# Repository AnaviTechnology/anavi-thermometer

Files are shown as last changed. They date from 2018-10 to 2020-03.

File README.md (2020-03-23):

# ANAVI Thermometer

ANAVI Thermometer is an open source hardware development board that acts like a WiFi smart thermometer. It features:

* ESP8266 WiFi microcontroller
* DHT22 sensor for temperature and humidity
* Terminal for waterproof DS18B20 1-Wire temperature sensor
* Dedicated slot for I2C OLED display
* Slots for up to 3 plug and play I2C sensors for temperature, barometric pressure, humidity and light
* UART (Universal asynchronous receiver/transmitter) pins for debugging

The default open source firmware for ANAVI Thermometer written as an [Arduino sketch is also available at GitHub](https://github.com/AnaviTechnology/anavi-thermometer-sw).

# License

The project is released under the [Creative Commons Attribution-ShareAlike 4.0 International (CC BY-SA 4.0)](https://creativecommons.org/licenses/by-sa/4.0/).

Note: This is a human-readable summary of (and not a substitute for) the [license](https://creativecommons.org/licenses/by-sa/4.0/legalcode).

You are free to:

Share — copy and redistribute the material in any medium or format Adapt — remix, transform, and build upon the material for any purpose, even commercially. The licensor cannot revoke these freedoms as long as you follow the license terms. Under the following terms:

Attribution — You must give appropriate credit, provide a link to the license, and indicate if changes were made. You may do so in any reasonable manner, but not in any way that suggests the licensor endorses you or your use. ShareAlike — If you remix, transform, or build upon the material, you must distribute your contributions under the same license as the original. No additional restrictions — You may not apply legal terms or technological measures that legally restrict others from doing anything the license permits. Notices:

You do not have to comply with the license for elements of the material in the public domain or where your use is permitted by an applicable exception or limitation. No warranties are given. The license may not give you all of the permissions necessary for your intended use. For example, other rights such as publicity, privacy, or moral rights may limit how you use the material.

You will have to provide a link to the original creator of the project http://www.anavi.technology on any documentation or website.

Credit can be attributed through a link to the creator website: http://www.anavi.technology

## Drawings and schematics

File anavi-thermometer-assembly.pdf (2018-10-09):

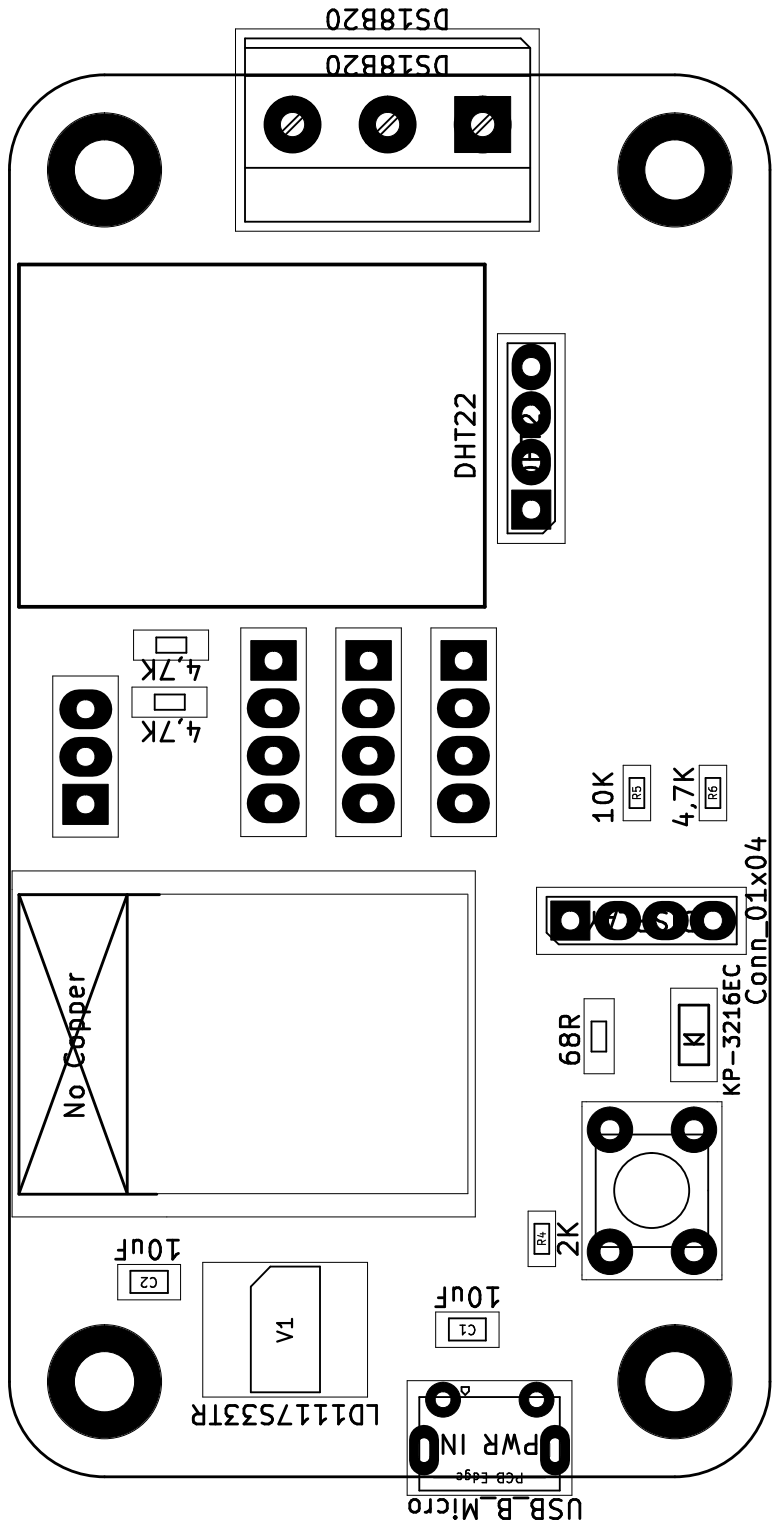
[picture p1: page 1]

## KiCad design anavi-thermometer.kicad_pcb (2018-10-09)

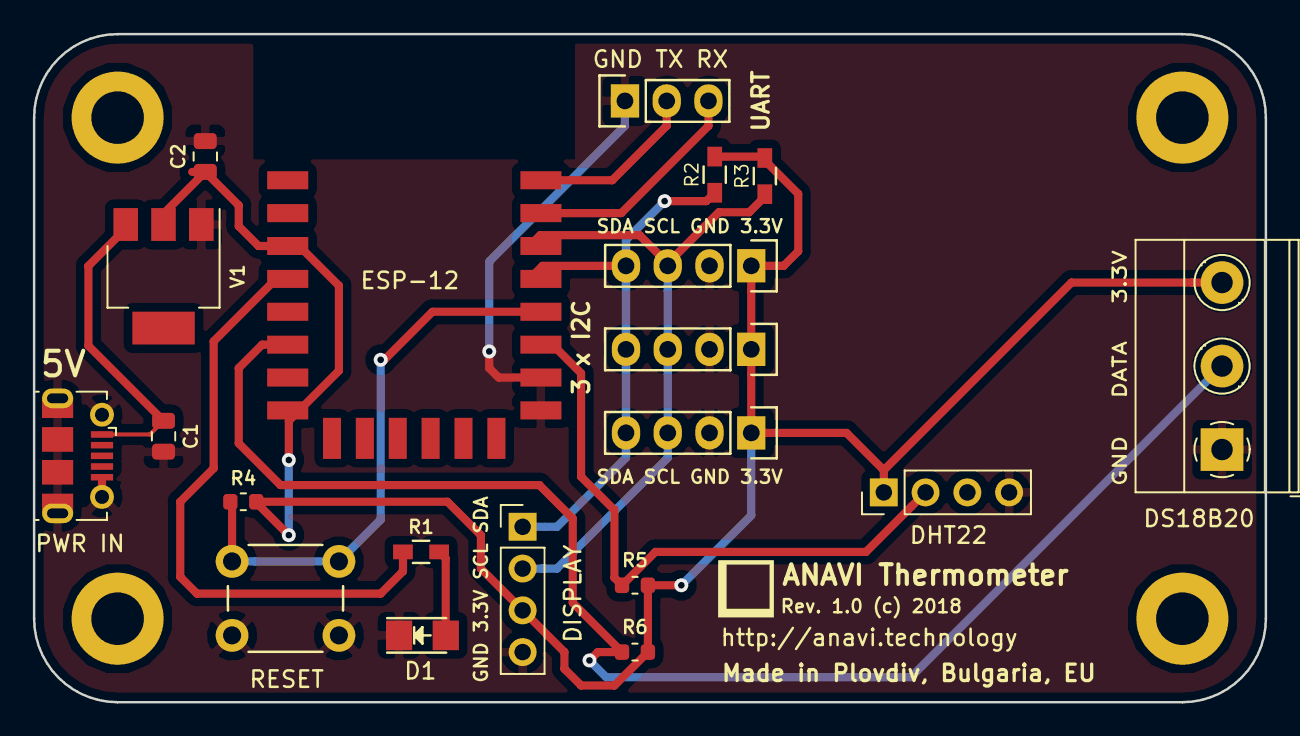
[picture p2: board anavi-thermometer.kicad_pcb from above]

Board: 2 copper layers, 74.9 x 40.6 mm, 20 parts (0 on the bottom side), 12 nets.

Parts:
C1, C2: 10uF; C_0805_2012Metric
D1: LED; LED_1206
DHT22: DHT22; PinHeader_1x04_P2.54mm_Vertical
DISPLAY: Conn_01x04; PinHeader_1x04_P2.54mm_Vertical
DS18B20: DS18B20; TerminalBlock_Phoenix_MKDS-1,5-3-5.08_1x03_P5.08mm_Horizont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
ESP-12: ESP-12E; ESP-12E_SMD
P1: CONN_01X03; Pin_Header_Straight_1x03
PWR IN: USB_B_Micro; USB_Micro-B_Molex-105017-0001
R1: 68R; R_0603_HandSoldering
R2, R3: 4,7K; R_0603_HandSoldering
R4: 2K; R_0603_1608Metric
R5: 10K; R_0603_1608Metric
R6: 4,7K; R_0603_1608Metric
RESET: SW_DIP_x01; SW_PUSH_6mm_h4.3mm
U1, U2, U3: I2C_SENS_1; Pin_Header_Straight_1x04
V1: LD1117S33TR; SOT-223

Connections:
+3V3: C2.1, DHT22.1, DISPLAY.3, DS18B20.3, ESP-12.3, ESP-12.8, R2.1, R3.1, R4.2, R5.1, R6.1, U1.1, U2.1, U3.1, V1.2
+5V: C1.1, PWR IN.1, V1.3
GND: C1.2, C2.2, D1.1, DHT22.4, DISPLAY.4, DS18B20.1, ESP-12.9, ESP-12.10, P1.1, PWR IN.5, PWR IN.6, RESET.1, U1.2, U2.2, U3.2, V1.1
unnamed: D1.2, R1.2
unnamed: ESP-12.4, R1.1
unnamed: DS18B20.2, ESP-12.6, R6.2
unnamed: DHT22.2, ESP-12.11, R5.2
unnamed: ESP-12.12, R4.1, RESET.2
unnamed: DISPLAY.1, ESP-12.13, R2.2, U1.4, U2.4, U3.4
unnamed: DISPLAY.2, ESP-12.14, R3.2, U1.3, U2.3, U3.3
unnamed: ESP-12.15, P1.3
unnamed: ESP-12.16, P1.2

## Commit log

2018-09-21 anavi-thermometer: Intial commit
    [anavi-light-controller-2018-09-18-17-42-49.sch, anavi-light-controller-2018-09-19-00-00-35.sch, anavi-light-controller-2018-09-19-09-35-14.sch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]
2018-09-21 anavi-thermometer.kicad_pcb: Update silkscreen
    Move the contour of DHT22 to the fab layer.
    [anavi-thermometer.kicad_pcb]
2018-09-24 anavi-thermometer.kicad_pcb: Update silkscreen
    [anavi-thermometer.kicad_pcb]
2018-09-29 anavi-thermometer.kicad_pcb: Fix UART silkscreen
    Fix silkscreen for UART.
    [anavi-thermometer.kicad_pcb]
2018-10-09 anavi-thermometer.kicad_pcb: Assembly guidelines
    Add guidelines for easier SMT assembly.
    [anavi-thermometer.kicad_pcb]
2020-03-23 README.md: Fix broken link to the Arduino sketch
    Fix broken link and add details.

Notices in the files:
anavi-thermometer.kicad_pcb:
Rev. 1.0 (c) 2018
